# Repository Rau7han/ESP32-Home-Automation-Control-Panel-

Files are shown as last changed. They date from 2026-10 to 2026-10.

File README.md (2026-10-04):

# DIY ESP32 Touchscreen Home Automation Control Panel

A simple DIY home automation project using an ESP32 touchscreen panel and an ESP32 relay node.

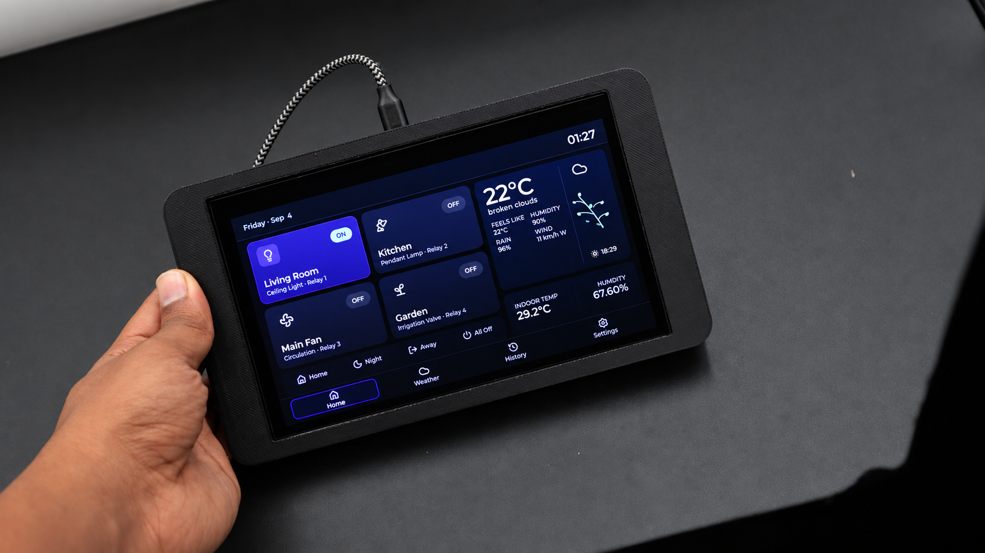
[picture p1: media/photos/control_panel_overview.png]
ESP32 Touchscreen Home Automation Control Panel


## Main Features

- Touchscreen dashboard for controlling home devices
- 4-channel relay control node
- ESP-NOW communication between display and relay board
- DHT22 temperature and humidity support on the relay node

## Hardware / Files Included

- **Display firmware:** `source-code/smart-panel-display/`
- **Relay node firmware:** `source-code/relay-node/`
- **PCB and schematic files (KiCad):** `hardware/pcb/esp32-4-channel-relays/`
- **3D enclosure file:** `hardware/3d/touchscreen_enclosure.3mf`
- **Project photos and diagrams:** `media/photos/`

## Where to Find What

- Use `source-code/` for all Arduino/ESP32 source files.
- Use `hardware/pcb/` for PCB design files.
- Use `hardware/3d/` for enclosure/3D files.
- Use `media/photos/` for project photos and visuals.

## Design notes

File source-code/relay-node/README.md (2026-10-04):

# ESP32 Relay + DHT22 Node

This folder is the relay-side firmware for the Smart Dashboard display.

## Wiring

- DHT22 VCC: 3.3 V
- DHT22 OUT: GPIO 13
- DHT22 GND: GND
- Relay 1: GPIO 26
- Relay 2: GPIO 25
- Relay 3: GPIO 33
- Relay 4: GPIO 32
- Display and relay boards must join the same 2.4 GHz Wi-Fi network

The sketch defaults to active-LOW relay modules. Set `RELAY_ACTIVE_LOW` to `0`
before connecting loads if the module is active HIGH.

## Dependency

Install **DHT sensor library** by Adafruit. Its **Adafruit Unified Sensor**
dependency is installed automatically. This project was compiled with DHT
library 1.4.7 and Arduino-ESP32 3.3.11.

A 3-pin DHT22 module normally includes the required data pull-up resistor. If
using a bare 4-pin sensor, add a 4.7–10 kΩ resistor between OUT and 3.3 V.

## Safety

All relay outputs are driven to OFF before their pins become outputs. Confirm
relay polarity with LEDs or a multimeter before connecting mains voltage.

The OpenWeather key belongs only in the display's private `secrets.h`; this
relay node does not make weather requests.

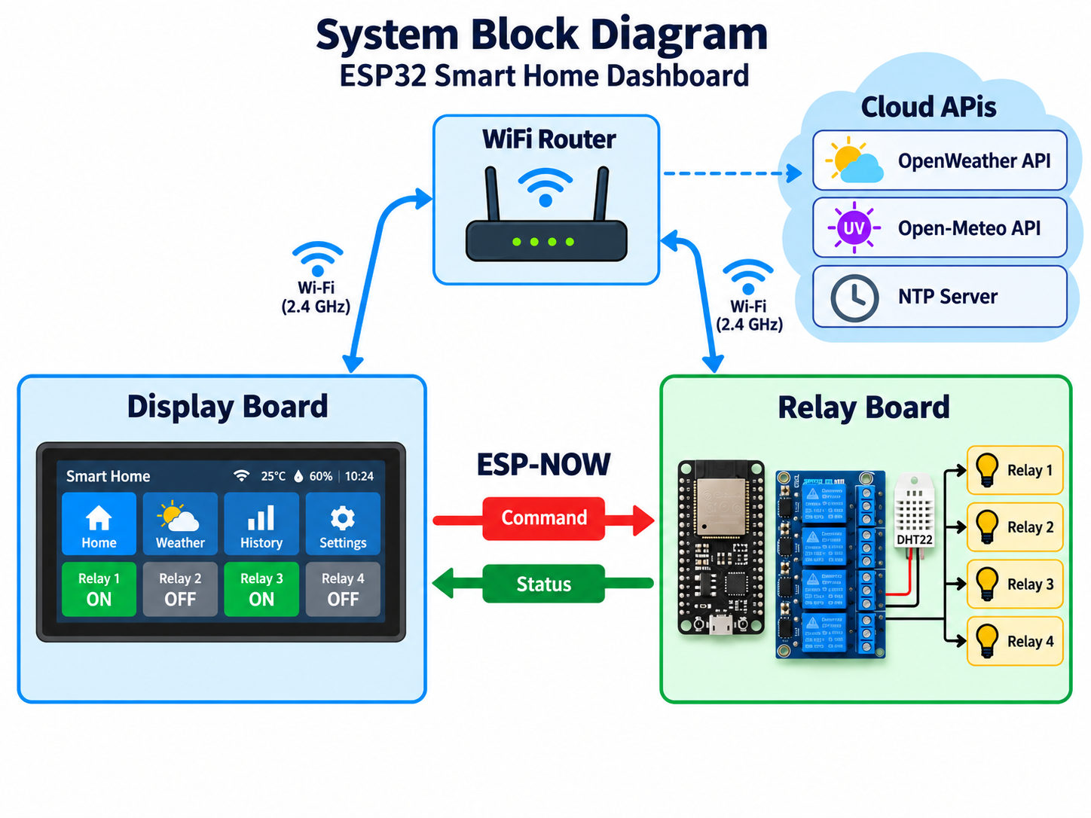
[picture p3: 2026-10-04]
media/photos/concept_render.png

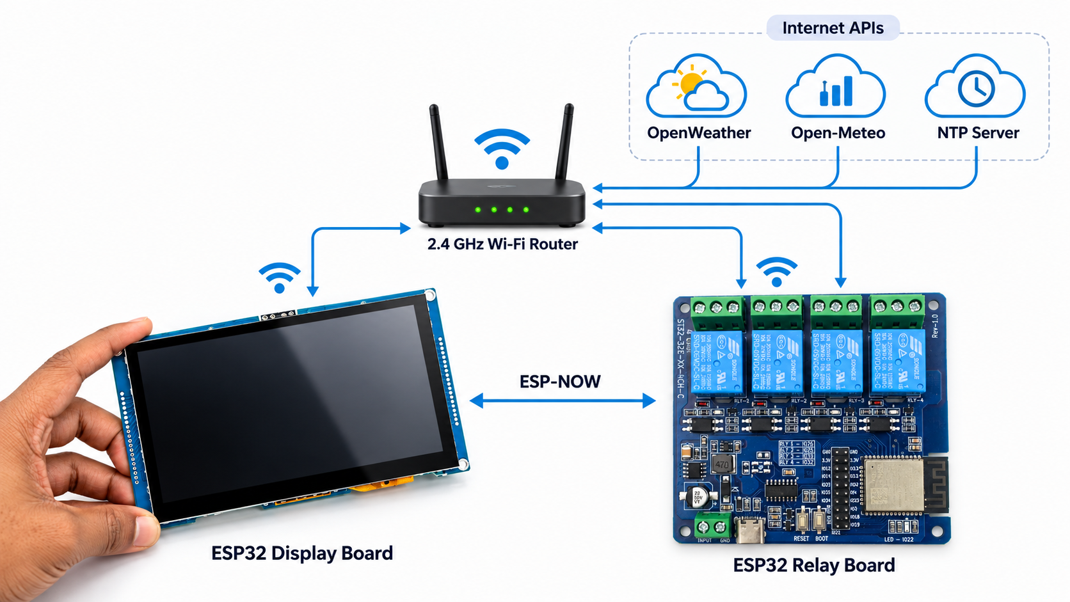
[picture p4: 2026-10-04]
media/photos/system_flow_overview.png

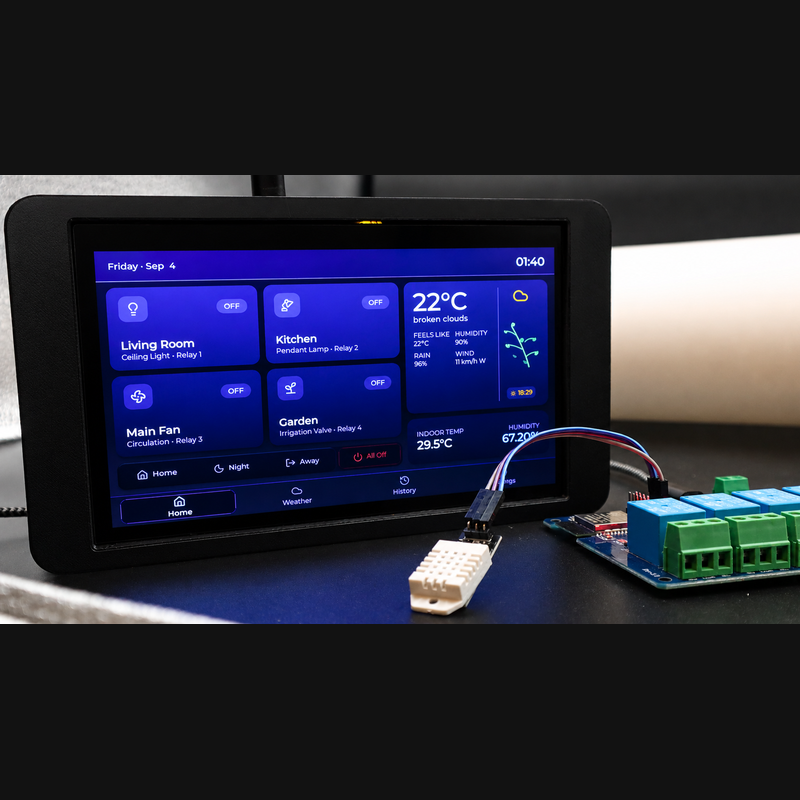
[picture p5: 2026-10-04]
media/photos/smart_home_thumbnail.png

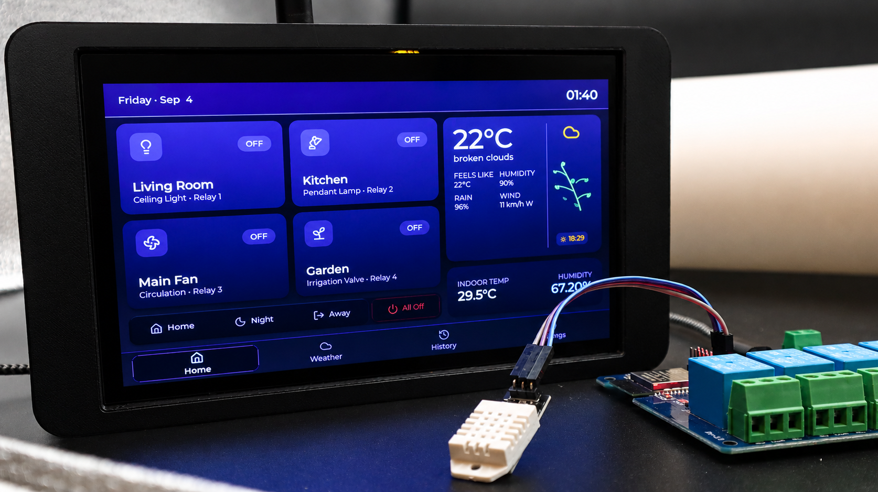
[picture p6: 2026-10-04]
media/photos/esp32_dashboard.png

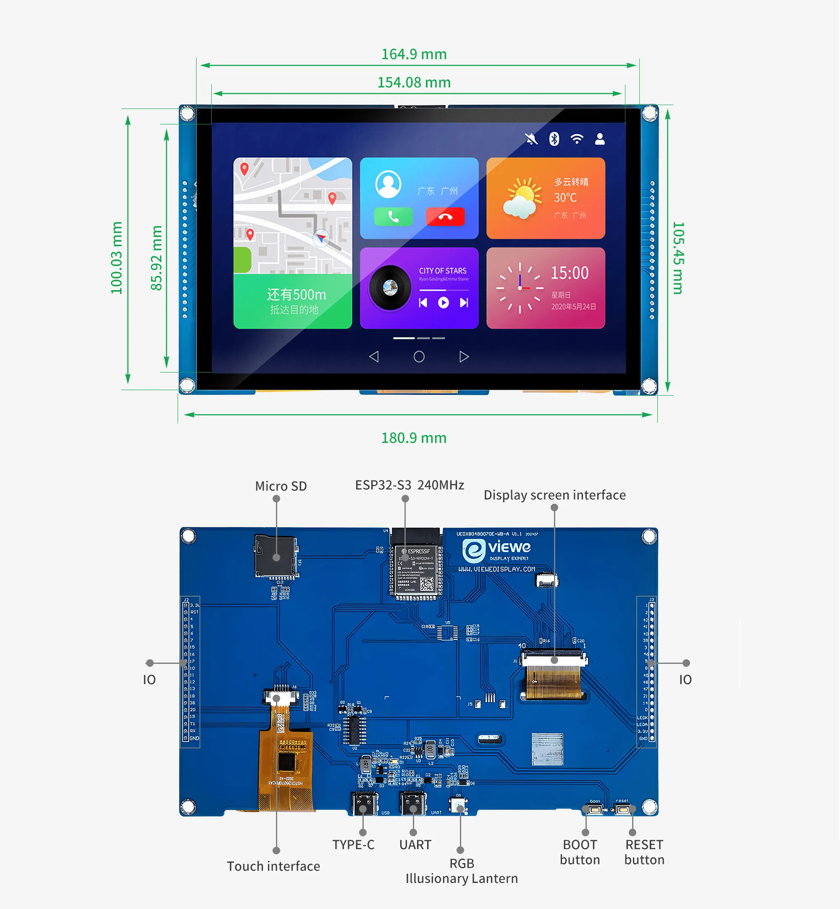
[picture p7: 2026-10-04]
media/photos/product_info_sheet.webp

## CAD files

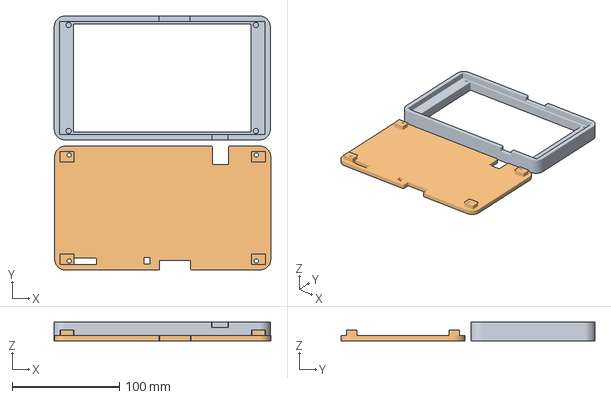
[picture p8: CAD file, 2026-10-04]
hardware/3d/touchscreen_enclosure.3mf
202.0 x 236.9 x 17.6 mm
7 Screen Case_F.stl
UEDX8048007OE-WB-A_back.stl

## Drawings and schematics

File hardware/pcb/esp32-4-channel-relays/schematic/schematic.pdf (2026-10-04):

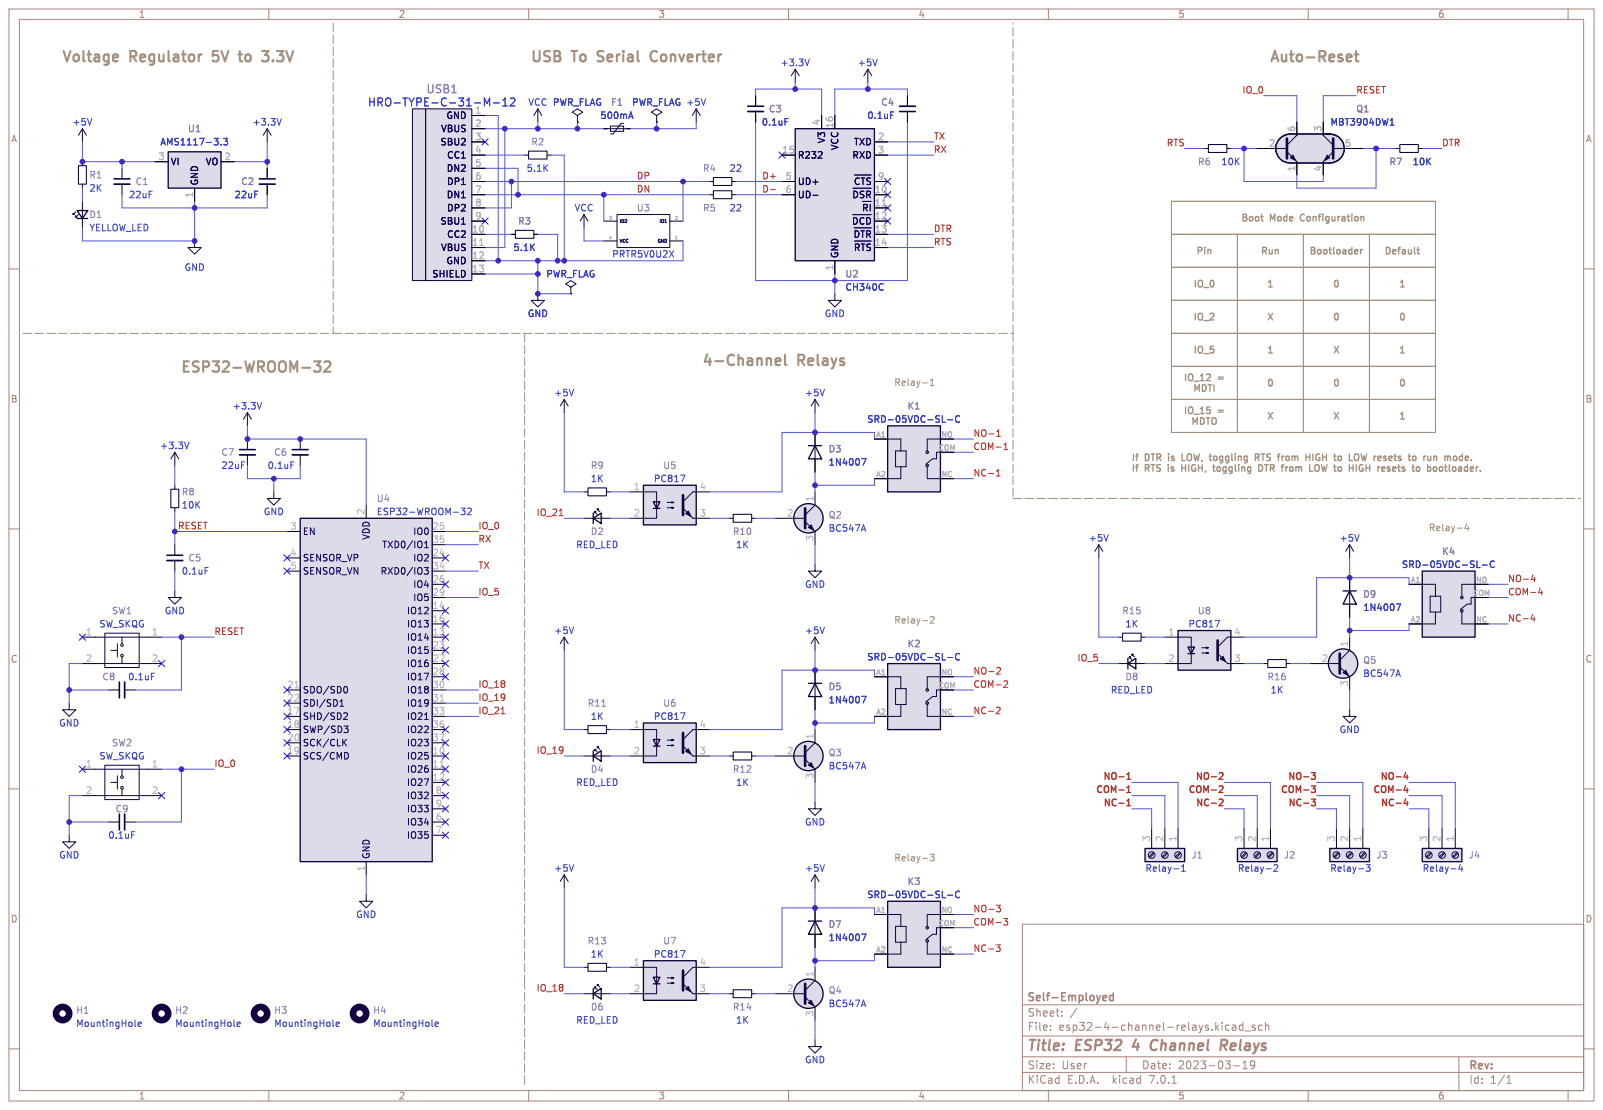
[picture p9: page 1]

GND 1 CC2 10 VBUS 11 GND 12 SHIELD 13 VBUS 2 SBU2 3 CC1 4 DN2 5 DP1 6 DN1 7 DP2 8 SBU1 9 USB1

4 UD+ 5 UD- 6 ~{CTS}9 U2 CH340C GND

1 ~{DSR} 10 ~{RI} 11 ~{DCD} 12 ~{DTR} 13 ~{RTS} 14 R232 15 VCC 16 TXD 2 RXD 3 V3

File: esp32-4-channel-relays.kicad_sch Sheet: / Self-Employed GND

4 UD+ 5 UD- 6 ~{CTS}9 K2 SRD-05VDC-SL-C

If RTS is HIGH, toggling DTR from LOW to HIGH resets to bootloader. Relay-1

If DTR is LOW, toggling RTS from HIGH to LOW resets to run mode.

2 SCK/CLK 20 SDO/SD0 21 SDI/SD1 22

Id: 1/1 Title: ESP32 4 Channel Relays

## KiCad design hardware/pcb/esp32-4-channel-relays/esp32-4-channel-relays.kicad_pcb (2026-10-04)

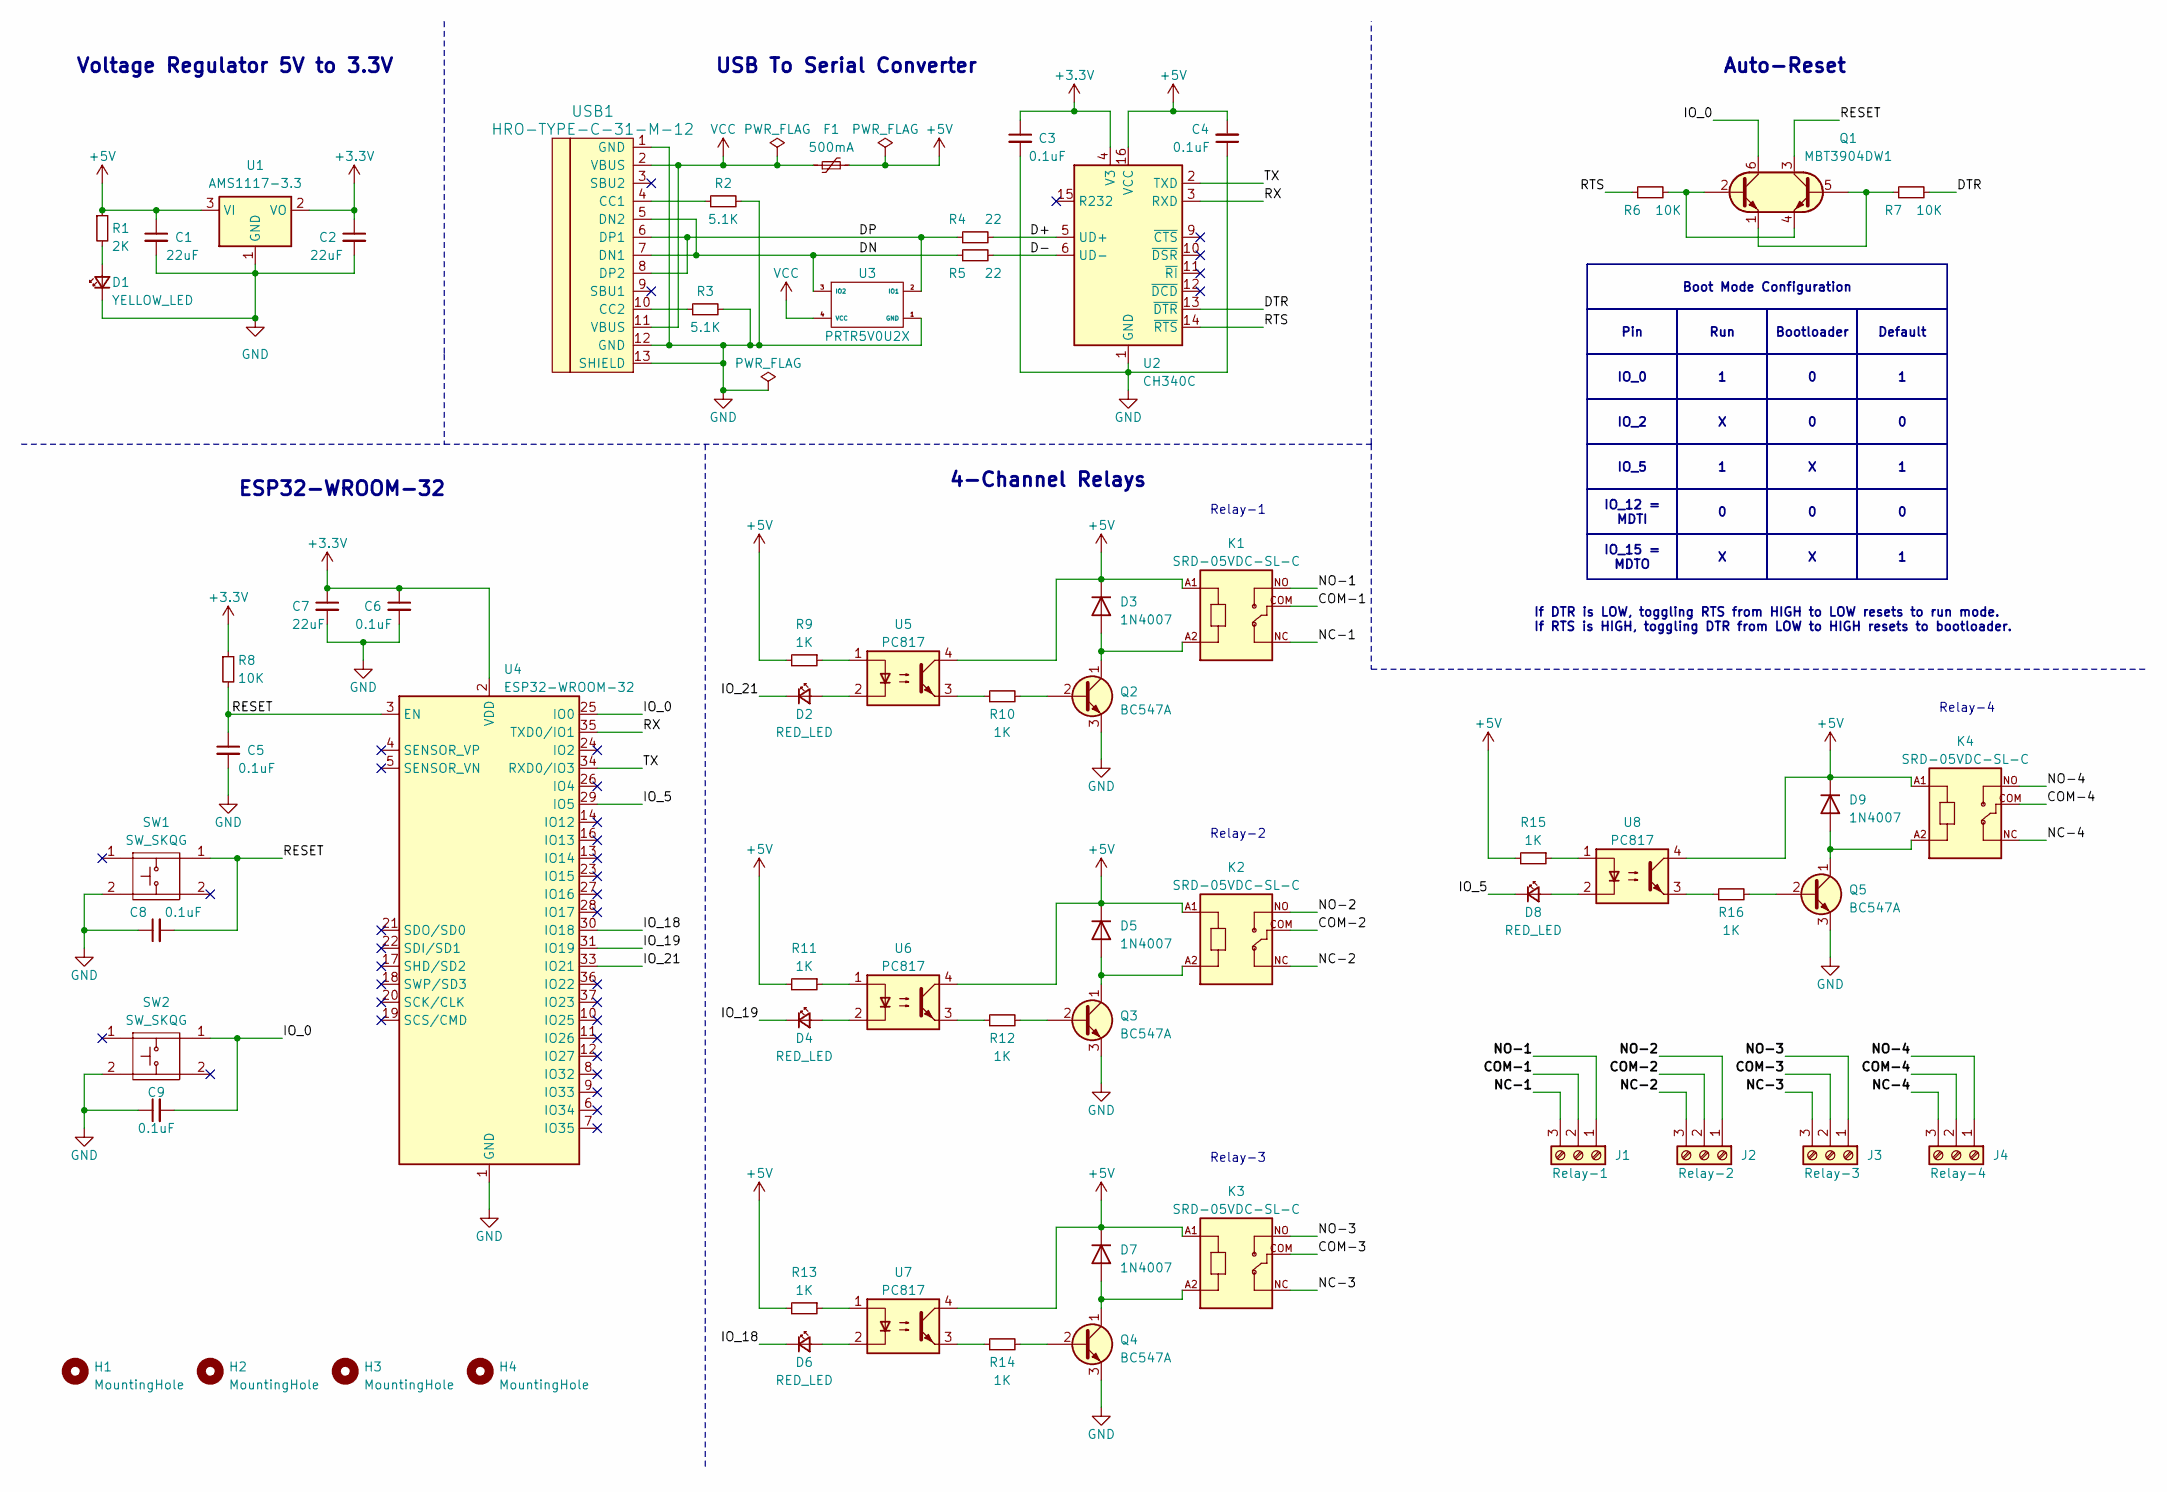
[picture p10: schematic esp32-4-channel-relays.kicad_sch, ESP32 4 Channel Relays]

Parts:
C1, C2, C7: 22uF; C_0805_2012Metric_Pad1.18x1.45mm_HandSolder
C3, C4, C5, C6, C8, C9: 0.1uF; C_0805_2012Metric_Pad1.18x1.45mm_HandSolder
D1: YELLOW_LED; LED_0805_2012Metric_Pad1.15x1.40mm_HandSolder
D2, D4, D6, D8: RED_LED; LED_0805_2012Metric_Pad1.15x1.40mm_HandSolder
D3, D5, D7, D9: 1N4007; D_MELF_Handsoldering
F1: 500mA; Fuse_1206_3216Metric_Pad1.42x1.75mm_HandSolder
H1, H2, H3, H4: MountingHole; MountingHole_3.2mm_M3
J1: Relay-1; TerminalBlock_Phoenix_MKDS-1,5-3-5.08_1x03_P5.08mm_Horizont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
J2: Relay-2; TerminalBlock_Phoenix_MKDS-1,5-3-5.08_1x03_P5.08mm_Horizont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
J3: Relay-3; TerminalBlock_Phoenix_MKDS-1,5-3-5.08_1x03_P5.08mm_Horizont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
J4: Relay-4; TerminalBlock_Phoenix_MKDS-1,5-3-5.08_1x03_P5.08mm_Horizont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
K1, K2, K3, K4: SRD-05VDC-SL-C; RELAY_SRD-05VDC-SL-C
Q1: MBT3904DW1; SOT-363_SC-70-6_Handsoldering
Q2, Q3, Q4, Q5: BC547A; TSOT-23_HandSoldering
R1: 2K; R_0805_2012Metric_Pad1.20x1.40mm_HandSolder
R2, R3: 5.1K; R_0805_2012Metric_Pad1.20x1.40mm_HandSolder
R4, R5: 22; R_0805_2012Metric_Pad1.20x1.40mm_HandSolder
R6, R7, R8: 10K; R_0805_2012Metric_Pad1.20x1.40mm_HandSolder
R9, R10, R11, R12, R13, R14, R15, R16: 1K; R_0805_2012Metric_Pad1.20x1.40mm_HandSolder
SW1, SW2: SW_SKQG; SW_SPST_SKQG_WithStem
U1: AMS1117-3.3; SOT-223-3_TabPin2
U2: CH340C; SOIC-16_3.9x9.9mm_P1.27mm
U3: PRTR5V0U2X; SOT-143_Handsoldering
U4: ESP32-WROOM-32
U5, U6, U7, U8: PC817; SMDIP-4_W7.62mm
USB1: HRO-TYPE-C-31-M-12; HRO-TYPE-C-31-M-12-HandSoldering

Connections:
+3.3V: C2.1, C3.1, C6.1, C7.1, R8.1, U1.2 (VO), U2.4 (V3), U4.2 (VDD)
+5V: C1.1, C4.2, D3.1 (K), D5.1 (K), D7.1 (K), D9.1 (K), F1.2, K1.A1, K2.A1, K3.A1, K4.A1, R1.1, R9.2, R11.2, R13.2, R15.2, U1.3 (VI), U2.16 (VCC), U5.4, U6.4, U7.4, U8.4
/COM-1: J1.2, K1.COM
/COM-2: J2.2, K2.COM
/COM-3: J3.2, K3.COM
/COM-4: J4.2, K4.COM
/D+: R4.2, U2.5 (UD+)
/D-: R5.2, U2.6 (UD-)
/DN: R5.1, U3.3 (IO2), USB1.5 (DN2), USB1.7 (DN1)
/DP: R4.1, U3.2 (IO1), USB1.6 (DP1), USB1.8 (DP2)
/DTR: R7.2, U2.13 (~DTR)
/IO_0: C9.2, Q1.6 (C1), SW2.1, U4.25 (IO0)
/IO_5: D8.1 (K), U4.29 (IO5)
/IO_18: D6.1 (K), U4.30 (IO18)
/IO_19: D4.1 (K), U4.31 (IO19)
/IO_21: D2.1 (K), U4.33 (IO21)
/NC-1: J1.3, K1.NC
/NC-2: J2.3, K2.NC
/NC-3: J3.3, K3.NC
/NC-4: J4.3, K4.NC
/NO-1: J1.1, K1.NO
/NO-2: J2.1, K2.NO
/NO-3: J3.1, K3.NO
/NO-4: J4.1, K4.NO
/RESET: C5.1, C8.2, Q1.3 (C2), R8.2, SW1.1, U4.3 (EN)
/RTS: R6.1, U2.14 (~RTS)
/RX: U2.3 (RXD), U4.35 (TXD0/IO1)
/TX: U2.2 (TXD), U4.34 (RXD0/IO3)
GND: C1.2, C2.2, C3.2, C4.1, C5.2, C6.2, C7.2, C8.1, C9.1, D1.1 (K), Q2.3 (E), Q3.3 (E), Q4.3 (E), Q5.3 (E), R2.2, R3.2, SW1.2, SW2.2, U1.1 (GND), U2.1 (GND), U3.1 (GND), U4.1 (GND), U4.15 (GND), U4.38 (GND), U4.39 (GND), USB1.1 (GND), USB1.12 (GND), USB1.13 (SHIELD)
unnamed: D1.2 (A), R1.2
unnamed: D2.2 (A), U5.2
unnamed: D3.2 (A), K1.A2, Q2.1 (C)
unnamed: D4.2 (A), U6.2
unnamed: D5.2 (A), K2.A2, Q3.1 (C)
unnamed: D6.2 (A), U7.2
unnamed: D7.2 (A), K3.A2, Q4.1 (C)
unnamed: D8.2 (A), U8.2
unnamed: D9.2 (A), K4.A2, Q5.1 (C)
unnamed: Q1.2 (B1), Q1.4 (E2), R6.2
unnamed: Q1.1 (E1), Q1.5 (B2), R7.1
unnamed: Q2.2 (B), R10.2
unnamed: Q3.2 (B), R12.2
unnamed: Q4.2 (B), R14.2
unnamed: Q5.2 (B), R16.2
unnamed: R9.1, U5.1
unnamed: R10.1, U5.3
unnamed: R11.1, U6.1
unnamed: R12.1, U6.3
unnamed: R13.1, U7.1
unnamed: R14.1, U7.3
unnamed: R15.1, U8.1
unnamed: R16.1, U8.3
unnamed: R2.1, USB1.4 (CC1)
unnamed: R3.1, USB1.10 (CC2)
VCC: F1.1, U3.4 (VCC), USB1.2 (VBUS), USB1.11 (VBUS)

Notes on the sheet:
Default
IO_2
IO_15 = MDTO
Bootloader
IO_0
IO_12 = MDTI
Run
Boot Mode Configuration
IO_5
Pin
Voltage Regulator 5V to 3.3V
4-Channel Relays
Relay-1
Relay-4
Relay-3
Relay-2
Auto-Reset
ESP32-WROOM-32
If DTR is LOW, toggling RTS from HIGH to LOW resets to run mode. If RTS is HIGH, toggling DTR from LOW to HIGH resets to bootloader.
USB To Serial Converter

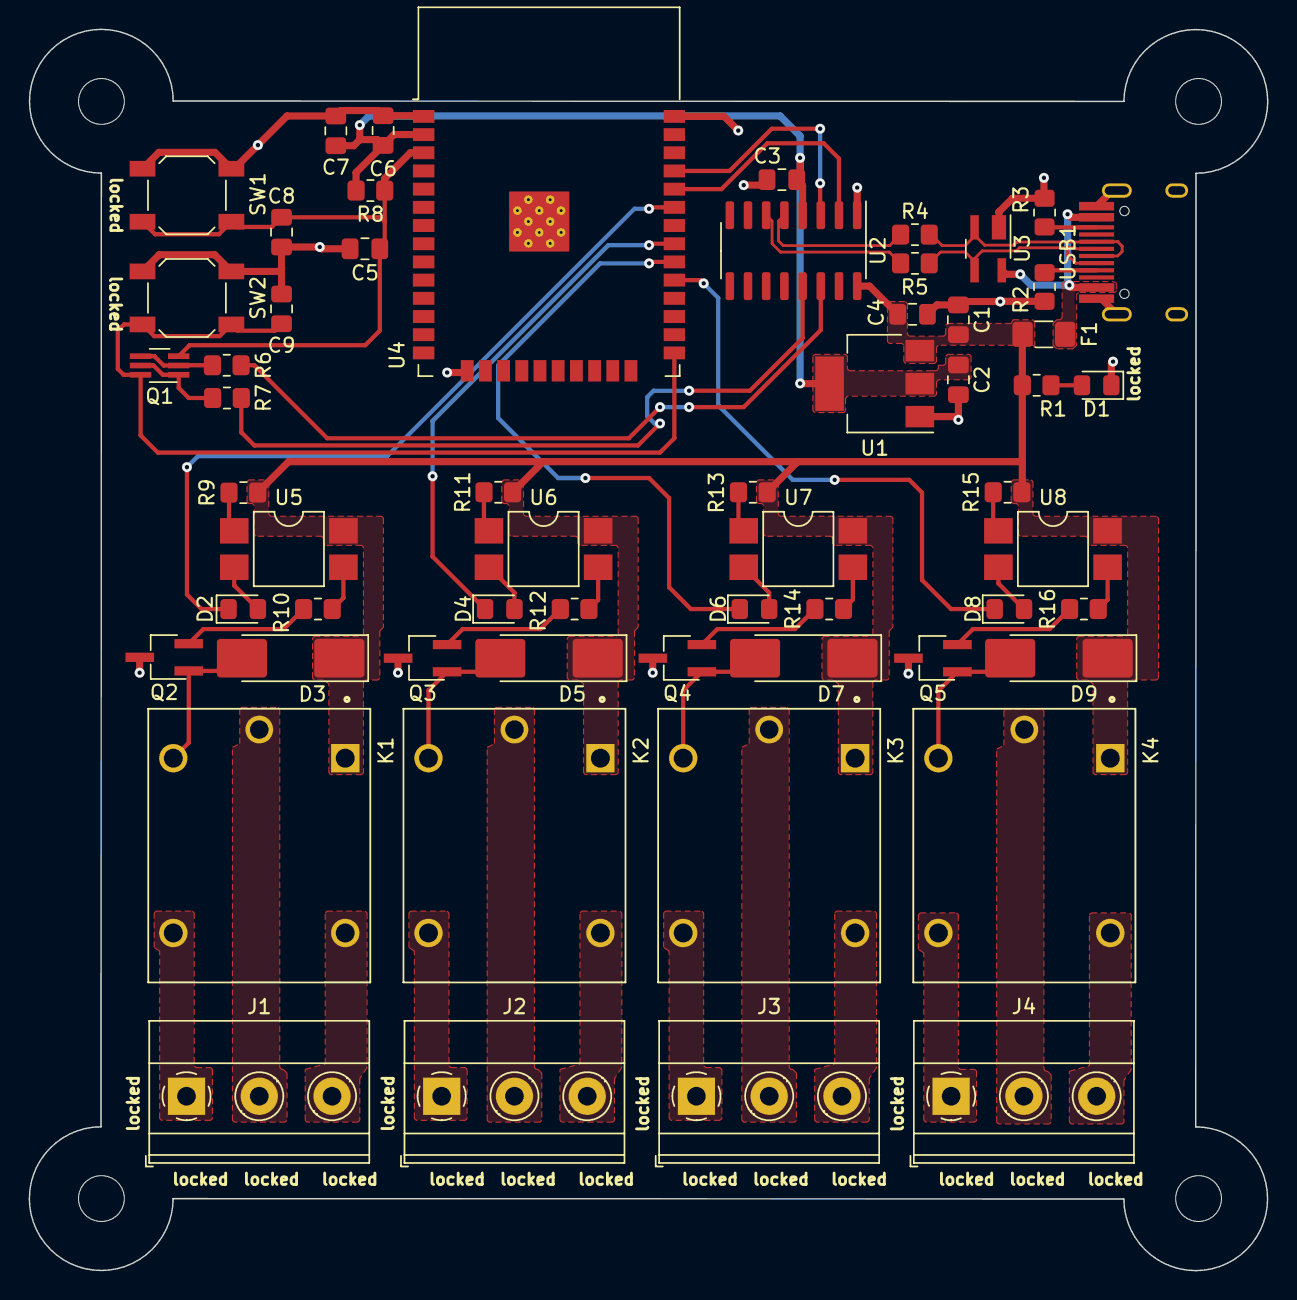
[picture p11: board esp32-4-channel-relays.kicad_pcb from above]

Board: 2 copper layers, 86.4 x 86.6 mm, 63 parts (0 on the bottom side), 55 nets.

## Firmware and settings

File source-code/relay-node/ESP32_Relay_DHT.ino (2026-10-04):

/**
 * ESP32 relay and DHT22 node for the Smart Dashboard.
 *
 * Hardware:
 *   DHT22 data GPIO 13
 *   Relay outputs GPIO 26, 25, 33, 32
 *
 * The node joins the same Wi-Fi network as the display so ESP-NOW uses the
 * router channel. Relay outputs change only after a valid command from the
 * configured display MAC. Every command is followed by a confirmed status
 * packet; periodic status packets keep the display's online state fresh.
 */

#include <Arduino.h>
#include <WiFi.h>
#include <esp_now.h>
#include <esp_mac.h>
#include <DHT.h>

#include "espnow_protocol.h"
#include "relay_secrets.h"

#define DHT_PIN 13
#define DHT_TYPE DHT22

#define RELAY1 26
#define RELAY2 25
#define RELAY3 33
#define RELAY4 32

/* Most opto-isolated relay modules are active LOW. Change this to 0 before
 * connecting loads if your module is active HIGH. Boot always requests OFF. */
#define RELAY_ACTIVE_LOW 1

static constexpr uint8_t RELAY_COUNT = 4;
static constexpr uint8_t RELAY_MASK_ALL = 0x0F;
static constexpr uint32_t STATUS_INTERVAL_MS = 2000;
static constexpr uint32_t SENSOR_INTERVAL_MS = 5000;
static constexpr uint32_t SENSOR_STALE_MS = 15000;

static const uint8_t RELAY_PINS[RELAY_COUNT] = {
    RELAY1, RELAY2, RELAY3, RELAY4
};

static const uint8_t DISPLAY_ESP32_MAC[6] = {
    0xFC, 0x01, 0x2C, 0xD4, 0x9C, 0x38
};

static const uint8_t EXPECTED_RELAY_MAC[6] = {
    0xC0, 0x5D, 0x89, 0xF5, 0xAD, 0xFC
};

enum CommandKind : uint8_t {
    COMMAND_RELAY,
    COMMAND_SCENE,
    COMMAND_STATUS
};

struct QueuedCommand {
    CommandKind kind;
    uint8_t relayIndex;
    uint8_t desiredState;
    uint8_t relayMask;
    uint32_t sequence;
};

struct SensorSnapshot {
    uint8_t validMask;
    int16_t temperatureCentiC;
    uint16_t humidityCentiPercent;
    uint32_t sampledAtMs;
};

static QueueHandle_t commandQueue = nullptr;
static DHT dht(DHT_PIN, DHT_TYPE);

static portMUX_TYPE sensorMux = portMUX_INITIALIZER_UNLOCKED;
static SensorSnapshot sensorSnapshot = {};
static volatile bool sensorStatusDirty = false;

static uint8_t confirmedRelayMask = 0;
static bool espNowReady = false;
static bool wifiWasConnected = false;
static uint32_t lastStatusSentMs = 0;
static uint32_t lastEspNowAttemptMs = 0;
static uint32_t lastConfirmedSequence = 0;

static bool macMatches(const uint8_t *a, const uint8_t *b)
{
    return a != nullptr && b != nullptr && memcmp(a, b, 6) == 0;
}

static uint8_t relayOffLevel()
{
    return RELAY_ACTIVE_LOW ? HIGH : LOW;
}

static uint8_t relayOnLevel()
{
    return RELAY_ACTIVE_LOW ? LOW : HIGH;
}

static void initializeRelayOutputs()
{
    confirmedRelayMask = 0;
    for (uint8_t i = 0; i < RELAY_COUNT; i++) {
        /* Set the output latch before enabling output mode to avoid an ON pulse. */
        digitalWrite(RELAY_PINS[i], relayOffLevel());
        pinMode(RELAY_PINS[i], OUTPUT);
        digitalWrite(RELAY_PINS[i], relayOffLevel());
    }
}

static void applyRelayMask(uint8_t mask)
{
    mask &= RELAY_MASK_ALL;
    for (uint8_t i = 0; i < RELAY_COUNT; i++) {
        bool on = (mask & (1U << i)) != 0;
        digitalWrite(RELAY_PINS[i], on ? relayOnLevel() : relayOffLevel());
    }
    confirmedRelayMask = mask;
}

static void sensorTask(void *parameter)
{
    (void)parameter;
    for (;;) {
        float humidity = dht.readHumidity();
        float temperature = dht.readTemperature();

        if (isnan(humidity) || isnan(temperature)) {
            Serial.println("DHT22 read failed; retaining last valid sample");
        } else {
            SensorSnapshot next = {};
            next.validMask = SENSOR_TEMP_VALID | SENSOR_HUMIDITY_VALID;
            next.temperatureCentiC =
                (int16_t)lroundf(temperature * 100.0f);
            humidity = constrain(humidity, 0.0f, 100.0f);
            next.humidityCentiPercent =
                (uint16_t)lroundf(humidity * 100.0f);
            next.sampledAtMs = millis();

            portENTER_CRITICAL(&sensorMux);
            sensorSnapshot = next;
            sensorStatusDirty = true;
            portEXIT_CRITICAL(&sensorMux);
        }

        vTaskDelay(pdMS_TO_TICKS(SENSOR_INTERVAL_MS));
    }
}

static void espNowSendCallback(
    const esp_now_send_info_t *info,
    esp_now_send_status_t status)
{
    (void)info;
    if (status != ESP_NOW_SEND_SUCCESS) {
        Serial.println("ESP-NOW status delivery failed");
    }
}

static void espNowReceiveCallback(
    const esp_now_recv_info_t *info,
    const uint8_t *data,
    int length)
{
    if (info == nullptr ||
        data == nullptr ||
        commandQueue == nullptr ||
        !macMatches(info->src_addr, DISPLAY_ESP32_MAC) ||
        length < 2 ||
        data[0] != ESPNOW_PROTOCOL_VERSION) {
        return;
    }

    QueuedCommand command = {};
    switch (data[1]) {
        case MSG_RELAY_COMMAND: {
            if (length != (int)sizeof(RelayCommandPacket)) return;
            RelayCommandPacket packet;
            memcpy(&packet, data, sizeof(packet));
            if (packet.relayIndex >= RELAY_COUNT || packet.desiredState > 1) return;
            command.kind = COMMAND_RELAY;
            command.relayIndex = packet.relayIndex;
            command.desiredState = packet.desiredState;
            command.sequence = packet.sequence;
            break;
        }
        case MSG_SCENE_COMMAND: {
            if (length != (int)sizeof(SceneCommandPacket)) return;
            SceneCommandPacket packet;
            memcpy(&packet, data, sizeof(packet));
            command.kind = COMMAND_SCENE;
            command.relayMask = packet.desiredRelayMask & RELAY_MASK_ALL;
            command.sequence = packet.sequence;
            break;
        }
        case MSG_STATUS_REQUEST: {
            if (length != (int)sizeof(StatusRequestPacket)) return;
            StatusRequestPacket packet;
            memcpy(&packet, data, sizeof(packet));
            command.kind = COMMAND_STATUS;
            command.sequence = packet.sequence;
            break;
        }
        default:
            return;
    }

    xQueueSend(commandQueue, &command, 0);
}

static bool initializeEspNow()
{
    if (espNowReady) return true;
    if (esp_now_init() != ESP_OK) {
        Serial.println("ESP-NOW initialization failed");
        return false;
    }

    if (esp_now_register_send_cb(espNowSendCallback) != ESP_OK ||
        esp_now_register_recv_cb(espNowReceiveCallback) != ESP_OK) {
        Serial.println("ESP-NOW callback registration failed");
        esp_now_deinit();
        return false;
    }

    esp_now_peer_info_t peer = {};
    memcpy(peer.peer_addr, DISPLAY_ESP32_MAC, 6);
    peer.channel = WiFi.channel();
    peer.ifidx = WIFI_IF_STA;
    peer.encrypt = false;

    esp_err_t result = esp_now_add_peer(&peer);
    espNowReady = result == ESP_OK || result == ESP_ERR_ESPNOW_EXIST;
    Serial.printf(
        "Display peer registration: %s (%d), channel %u\n",
        espNowReady ? "OK" : "FAILED",
        result,
        (unsigned)WiFi.channel());
    if (!espNowReady) esp_now_deinit();
    return espNowReady;
}

static void sendConfirmedStatus(uint32_t sequence)
{
    if (!espNowReady) return;

    SensorSnapshot sensor;
    portENTER_CRITICAL(&sensorMux);
    sensor = sensorSnapshot;
    portEXIT_CRITICAL(&sensorMux);

    if (sensor.sampledAtMs == 0 ||
        millis() - sensor.sampledAtMs > SENSOR_STALE_MS) {
        sensor.validMask = 0;
    }

    RelaySensorStatusPacket packet = {};
    packet.version = ESPNOW_PROTOCOL_VERSION;
    packet.type = MSG_RELAY_SENSOR_STATUS;
    packet.relayMask = confirmedRelayMask;
    packet.sensorValidMask = sensor.validMask;
    packet.sequence = sequence;
    packet.indoorTemperatureCentiC = sensor.temperatureCentiC;
    packet.indoorHumidityCentiPercent = sensor.humidityCentiPercent;
    packet.relayNodeUptimeMs = millis();

    esp_now_send(
        DISPLAY_ESP32_MAC,
        reinterpret_cast<const uint8_t *>(&packet),
        sizeof(packet));
    lastStatusSentMs = millis();
}

static void processCommandQueue()
{
    QueuedCommand command;
    while (commandQueue != nullptr &&
           xQueueReceive(commandQueue, &command, 0) == pdTRUE) {
        switch (command.kind) {
            case COMMAND_RELAY: {
                uint8_t bit = 1U << command.relayIndex;
                uint8_t desiredMask = command.desiredState
                    ? (confirmedRelayMask | bit)
                    : (confirmedRelayMask & ~bit);
                applyRelayMask(desiredMask);
                lastConfirmedSequence = command.sequence;
                Serial.printf(
                    "Relay %u confirmed %s, mask=0x%02X\n",
                    command.relayIndex + 1,
                    command.desiredState ? "ON" : "OFF",
                    confirmedRelayMask);
                sendConfirmedStatus(command.sequence);
                break;
            }
            case COMMAND_SCENE:
                applyRelayMask(command.relayMask);
                lastConfirmedSequence = command.sequence;
                Serial.printf(
                    "Scene confirmed, mask=0x%02X\n",
                    confirmedRelayMask);
                sendConfirmedStatus(command.sequence);
                break;
            case COMMAND_STATUS:
                sendConfirmedStatus(command.sequence);
                break;
        }
    }
}

static void initializeSensor()
{
    dht.begin();
    BaseType_t result = xTaskCreate(
        sensorTask, "dht22", 3072, nullptr, 1, nullptr);
    if (result == pdPASS) {
        Serial.printf("DHT22 ready on GPIO %u\n", DHT_PIN);
    } else {
        Serial.println("ERROR: DHT22 task creation failed");
    }
}

void setup()
{
    Serial.begin(115200);
    delay(500);
    Serial.println("\nESP32 Relay + DHT22 Node");
    Serial.printf(
        "Relay pins: %u, %u, %u, %u (%s)\n",
        RELAY1, RELAY2, RELAY3, RELAY4,
        RELAY_ACTIVE_LOW ? "active LOW" : "active HIGH");

    initializeRelayOutputs();
    initializeSensor();

    commandQueue = xQueueCreate(12, sizeof(QueuedCommand));
    if (commandQueue == nullptr) {
        Serial.println("ERROR: command queue allocation failed");
    }

    WiFi.mode(WIFI_STA);

    /* WiFi.macAddress() returns zeros until the Wi-Fi stack finishes starting,
     * so read the eFuse address directly. */
    uint8_t actualMac[6];
    esp_read_mac(actualMac, ESP_MAC_WIFI_STA);
    Serial.printf(
        "Relay STA MAC: %02X:%02X:%02X:%02X:%02X:%02X\n",
        actualMac[0], actualMac[1], actualMac[2],
        actualMac[3], actualMac[4], actualMac[5]);
    Serial.println("Expected relay MAC: C0:5D:89:F5:AD:FC");
    Serial.println("Display peer MAC: FC:01:2C:D4:9C:38");

    if (!macMatches(actualMac, EXPECTED_RELAY_MAC)) {
        Serial.println("WARNING: this board MAC differs from the configured relay peer MAC");
    }

    WiFi.setAutoReconnect(true);
    WiFi.setSleep(false);
    WiFi.begin(WIFI_SSID, WIFI_PASSWORD);
    Serial.println("Wi-Fi connection started");
}

void loop()
{
    uint32_t now = millis();
    bool connected = WiFi.status() == WL_CONNECTED;

    if (connected && !wifiWasConnected) {
        wifiWasConnected = true;
        Serial.printf(
            "Wi-Fi connected, IP=%s, channel=%u\n",
            WiFi.localIP().toString().c_str(),
            (unsigned)WiFi.channel());
        initializeEspNow();
        lastEspNowAttemptMs = now;
        sendConfirmedStatus(lastConfirmedSequence);
    } else if (!connected && wifiWasConnected) {
        wifiWasConnected = false;
        espNowReady = false;
        esp_now_deinit();
        Serial.println("Wi-Fi disconnected; relays keep their confirmed states");
    }

    if (connected && !espNowReady &&
        now - lastEspNowAttemptMs >= 5000) {
        lastEspNowAttemptMs = now;
        initializeEspNow();
    }

    processCommandQueue();

    if (espNowReady &&
        (sensorStatusDirty || now - lastStatusSentMs >= STATUS_INTERVAL_MS)) {
        sensorStatusDirty = false;
        sendConfirmedStatus(lastConfirmedSequence);
    }

    delay(10);
}

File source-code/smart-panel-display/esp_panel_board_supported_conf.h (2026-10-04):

/*
 * SPDX-FileCopyrightText: 2023-2025 Espressif Systems (Shanghai) CO LTD
 *
 * SPDX-License-Identifier: Apache-2.0
 */
/**
 * @file  esp_panel_board_supported_conf.h
 * @brief Configuration file for supported ESP development boards
 *
 * This file contains configuration options for various supported development boards using ESP Panel.
 * Users can select their specific board by uncommenting the corresponding macro definition.
 */

#pragma once

/**
 * @brief Flag to enable supported board configuration (0/1)
 *
 * Set to `1` to enable supported board configuration, `0` to disable
 */
#define ESP_PANEL_BOARD_DEFAULT_USE_SUPPORTED       (1)

#if ESP_PANEL_BOARD_DEFAULT_USE_SUPPORTED
/**
 * @brief Board selection macros
 *
 * Uncomment one of the following macros to select a supported development board. Multiple macros enabled
 * simultaneously will trigger a compilation error.
 */

/*
 * Espressif (https://www.espressif.com/en/products/devkits):
 *
 *  -BOARD_ESPRESSIF_ESP32_C3_LCDKIT (ESP32-C3-LCDkit): https://docs.espressif.com/projects/esp-dev-kits/en/latest/esp32c3/esp32-c3-lcdkit/index.html
 *  -BOARD_ESPRESSIF_ESP32_S3_BOX (ESP32-S3-Box): https://github.com/espressif/esp-box/tree/master
 *  -BOARD_ESPRESSIF_ESP32_S3_BOX_3 (ESP32-S3-Box-3 & ESP32-S3-Box-3B): https://github.com/espressif/esp-box/tree/master
 *  -BOARD_ESPRESSIF_ESP32_S3_BOX_3_BETA (ESP32-S3-Box-3(beta)): https://github.com/espressif/esp-box/tree/c4c954888e11250423f083df0067d99e22d59fbe
 *  -BOARD_ESPRESSIF_ESP32_S3_BOX_LITE (ESP32-S3-Box-Lite): https://github.com/espressif/esp-box/tree/master
 *  -BOARD_ESPRESSIF_ESP32_S3_EYE (ESP32-S3-EYE): https://github.com/espressif/esp-who/blob/master/docs/en/get-started/ESP32-S3-EYE_Getting_Started_Guide.md
 *  -BOARD_ESPRESSIF_ESP32_S3_KORVO_2 (ESP32-S3-Korvo-2): https://docs.espressif.com/projects/esp-adf/en/latest/design-guide/dev-boards/user-guide-esp32-s3-korvo-2.html
 *  -BOARD_ESPRESSIF_ESP32_S3_LCD_EV_BOARD (ESP32-S3-LCD-EV-Board(v1.1-v1.4)): https://docs.espressif.com/projects/esp-dev-kits/en/latest/esp32s3/esp32-s3-lcd-ev-board/user_guide_v1.4.html
 *  -BOARD_ESPRESSIF_ESP32_S3_LCD_EV_BOARD_V1_5 (ESP32-S3-LCD-EV-Board(v1.5)): https://docs.espressif.com/projects/esp-dev-kits/en/latest/esp32s3/esp32-s3-lcd-ev-board/user_guide.html
 *  -BOARD_ESPRESSIF_ESP32_S3_LCD_EV_BOARD_2 (ESP32-S3-LCD-EV-Board-2(v1.1-v1.4))): https://docs.espressif.com/projects/esp-dev-kits/en/latest/esp32s3/esp32-s3-lcd-ev-board/user_guide_v1.4.html
 *  -BOARD_ESPRESSIF_ESP32_S3_LCD_EV_BOARD_2_V1_5 (ESP32-S3-LCD-EV-Board-2(v1.5)): https://docs.espressif.com/projects/esp-dev-kits/en/latest/esp32s3/esp32-s3-lcd-ev-board/user_guide.html
 *  -BOARD_ESPRESSIF_ESP32_S3_USB_OTG (ESP32-S3-USB-OTG): https://docs.espressif.com/projects/esp-dev-kits/en/latest/esp32s3/esp32-s3-usb-otg/index.html
 *  -BOARD_ESPRESSIF_ESP32_P4_FUNCTION_EV_BOARD (ESP32-P4-Function-EV-Board): https://docs.espressif.com/projects/esp-dev-kits/en/latest/esp32p4/esp32-p4-function-ev-board/index.html
 */
// #define BOARD_ESPRESSIF_ESP32_C3_LCDKIT
// #define BOARD_ESPRESSIF_ESP32_S3_BOX
// #define BOARD_ESPRESSIF_ESP32_S3_BOX_3
// #define BOARD_ESPRESSIF_ESP32_S3_BOX_3_BETA
// #define BOARD_ESPRESSIF_ESP32_S3_BOX_LITE
// #define BOARD_ESPRESSIF_ESP32_S3_EYE
// #define BOARD_ESPRESSIF_ESP32_S3_KORVO_2
// #define BOARD_ESPRESSIF_ESP32_S3_LCD_EV_BOARD
// #define BOARD_ESPRESSIF_ESP32_S3_LCD_EV_BOARD_V1_5
// #define BOARD_ESPRESSIF_ESP32_S3_LCD_EV_BOARD_2
// #define BOARD_ESPRESSIF_ESP32_S3_LCD_EV_BOARD_2_V1_5
// #define BOARD_ESPRESSIF_ESP32_S3_USB_OTG
// #define BOARD_ESPRESSIF_ESP32_P4_FUNCTION_EV_BOARD

/*
 * Elecrow (https://www.elecrow.com):
 *
 *  -BOARD_ELECROW_CROWPANEL_7_0 (ELECROW_CROWPANEL_7_0): https://www.elecrow.com/esp32-display-7-inch-hmi-display-rgb-tft-lcd-touch-screen-support-lvgl.html
 */
// #define BOARD_ELECROW_CROWPANEL_7_0

/*
 * M5Stack (https://m5stack.com/):
 *
 *  -BOARD_M5STACK_M5CORE2 (M5STACK_M5CORE2): https://docs.m5stack.com/en/core/core2
 *  -BOARD_M5STACK_M5DIAL (M5STACK_M5DIAL): https://docs.m5stack.com/en/core/M5Dial
 *  -BOARD_M5STACK_M5CORES3 (M5STACK_M5CORES3): https://docs.m5stack.com/en/core/CoreS3
 */
// #define BOARD_M5STACK_M5CORE2
// #define BOARD_M5STACK_M5DIAL
// #define BOARD_M5STACK_M5CORES3

/*
 * Shenzhen Jingcai Intelligent Supported Boards (https://www.displaysmodule.com/):
 *
 *  -BOARD_JINGCAI_ESP32_4848S040C_I_Y_3 (ESP32-4848S040C_I_Y_3):
 *      - https://www.displaysmodule.com/sale-41828962-experience-the-power-of-the-esp32-display-module-sku-esp32-4848s040c-i-y-3.html
 *      - http://pan.jczn1688.com/directlink/1/ESP32%20module/4.0inch_ESP32-4848S040.zip
 *  -BOARD_JINGCAI_JC8048W550C (JC8048W550C):
 *      - https://www.displaysmodule.com/sale-43987867-capacitive-touch-advanced-tft-hmi-display-module-jc8048w550-800-480-pixel-resolution-st7262-driver-c.html
 */
// #define BOARD_JINGCAI_ESP32_4848S040C_I_Y_3
// #define BOARD_JINGCAI_JC8048W550C
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

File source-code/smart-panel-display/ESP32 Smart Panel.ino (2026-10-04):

/**
 * VIEWE UEDX80480070 7.0-inch ESP32-S3 Touch Display
 * Resolution: 800 x 480, IPS RGB interface / Touch: GT911 (I2C) / MCU: ESP32-S3
 *
 * Smart Home Panel UI (LVGL v8), Phase 1 display firmware.
 * Relay GPIO and DHT22 acquisition run on the separate relay-node firmware.
 */

#include <Arduino.h>
#include <Preferences.h>
#include <math.h>
#include <limits.h>
#include <WiFi.h>
#include <HTTPClient.h>
#include <ArduinoJson.h>
#include <esp_now.h>
#include <esp_mac.h>
#include <time.h>
#include <esp_display_panel.hpp>
#include <lvgl.h>
#include "lvgl_v8_port.h"
#include "dashboard_icons.h"
#include "espnow_protocol.h"

#if __has_include("secrets.h")
#include "secrets.h"
#define DASHBOARD_HAS_SECRETS 1
#else
#define DASHBOARD_HAS_SECRETS 0
#define WIFI_SSID ""
#define WIFI_PASSWORD ""
#define OPENWEATHER_KEY ""
#define WEATHER_LATITUDE ""
#define WEATHER_LONGITUDE ""
#define TIMEZONE_INFO "UTC0"
#endif

using namespace esp_panel::drivers;
using namespace esp_panel::board;

/* Only the degree sign and the bullet exist outside ASCII in the built-in
   fonts. Kept as macros so an adjacent hex digit cannot extend the escape. */
#define DEG  "\xC2\xB0"
#define MDOT " \xE2\x80\xA2 "

/* Type scale. Sizes below 12 px are deliberately absent: small grey text was
   unreadable on this panel, so 12 px is the floor and captions use text2. */
#define F_CAP   &lv_font_montserrat_12
#define F_BODY  &lv_font_montserrat_14
#define F_TITLE &lv_font_montserrat_16
#define F_RELAY &lv_font_montserrat_18
#define F_PAGE  &lv_font_montserrat_20
#define F_CLOCK &lv_font_montserrat_22
#define F_HERO  &lv_font_montserrat_46

#define RELAY_COUNT  4
#define SCENE_COUNT  4
#define HISTORY_MAX  8
#define REG_MAX      420

static constexpr uint32_t TOUCH_GUARD_MS = 180;
static constexpr uint32_t RELAY_PENDING_TIMEOUT_MS = 2500;
static constexpr uint32_t RELAY_OFFLINE_TIMEOUT_MS = 15000;
static constexpr uint32_t STATUS_REQUEST_INTERVAL_MS = 5000;
static constexpr uint32_t WEATHER_INTERVAL_MS = 10UL * 60UL * 1000UL;
static constexpr uint32_t WEATHER_RETRY_MS = 60UL * 1000UL;
static constexpr uint8_t RELAY_MASK_ALL = (1U << RELAY_COUNT) - 1;

static const uint8_t RELAY_ESP32_MAC[6] = {0xC0, 0x5D, 0x89, 0xF5, 0xAD, 0xFC};

/* =========================================================
   THEME PALETTES
   ========================================================= */
struct Palette {
    uint32_t bg, chrome, card, raised, sunken, border;
    uint32_t text, text2, text3;
    uint32_t accent, accent_soft, accent_bay, accent_line, accent_hi;
    uint32_t amber, violet, green, coral;
    uint32_t chart_past, grid, knob_off, icon_off;
    uint32_t nav_on[4];
    uint32_t relay_on[RELAY_COUNT];
    uint32_t scene_fg[SCENE_COUNT];
    uint32_t scene_soft[SCENE_COUNT];
    uint32_t scene_line[SCENE_COUNT];
};

enum { THEME_SLATE = 0, THEME_AMOLED = 1, THEME_AURORA = 2, THEME_COUNT = 3 };

static const Palette palettes[THEME_COUNT] = {
    /* ---- Slate: the original graphite look, with lifted greys for contrast ---- */
    {
        0x0D1117, 0x121821, 0x18202A, 0x202A36, 0x10161F, 0x2A3644,
        0xF3F6F8, 0xA9B6C4, 0x8A97A8,
        0x4E9BFF, 0x142232, 0x1D3B60, 0x335D8A, 0x7DB6FF,
        0xFFB84D, 0x8D8BEB, 0x61C786, 0xE4676B,
        0x8A97A8, 0x263341, 0x8A97A8, 0xA9B6C4,
        {0x7DB6FF, 0x7DB6FF, 0x7DB6FF, 0x7DB6FF},
        {0x7DB6FF, 0x7DB6FF, 0x7DB6FF, 0x7DB6FF},
        {0x7DB6FF, 0x8D8BEB, 0xFFB84D, 0xE4676B},
        {0x142232, 0x212038, 0x2A2218, 0x321A1E},
        {0x335D8A, 0x4A4785, 0x5C4325, 0x6E2D33},
    },
    /* ---- AMOLED: true black chrome for the panel's deepest state ---- */
    {
        0x000000, 0x07090C, 0x0F141A, 0x171E26, 0x05070A, 0x263039,
        0xFFFFFF, 0xB2BECB, 0x94A1AF,
        0x4E9BFF, 0x0E1A28, 0x16324F, 0x2F5680, 0x8CC0FF,
        0xFFC163, 0x9B99F5, 0x6FD494, 0xF07178,
        0x94A1AF, 0x1B242C, 0x94A1AF, 0xB2BECB,
        {0x8CC0FF, 0x8CC0FF, 0x8CC0FF, 0x8CC0FF},
        {0x8CC0FF, 0x8CC0FF, 0x8CC0FF, 0x8CC0FF},
        {0x8CC0FF, 0x9B99F5, 0xFFC163, 0xF07178},
        {0x0E1A28, 0x15142A, 0x231C12, 0x2A1216},
        {0x2F5680, 0x413E77, 0x543D22, 0x63272D},
    },
    /* ---- Aurora: deep navy with cyan/violet accents and per-icon hues ---- */
    {
        0x08111F, 0x101A33, 0x18284C, 0x223862, 0x0C1830, 0x315582,
        0xF8FAFF, 0xA9B7D0, 0x8C9CBA,
        0x32D5FF, 0x123A55, 0x1B4E6E, 0x2F7FA5, 0x7FE6FF,
        0xFFBF47, 0xA277FF, 0x4ADE80, 0xFF5D73,
        0x8C9CBA, 0x1E3559, 0x8C9CBA, 0x8C9CBA,
        {0x32D5FF, 0xFFBF47, 0xA277FF, 0x4ADE80},
        {0xFFE066, 0xFF9F4A, 0x32D5FF, 0x4ADE80},
        {0x32D5FF, 0xA277FF, 0xFFBF47, 0xFF5D73},
        {0x123A55, 0x2A2050, 0x3A2E14, 0x3A1723},
        {0x2F7FA5, 0x5B45A5, 0x7A5C24, 0x8A3140},
    },
};

/* Style roles. Every themed widget is tagged with one at creation time so a
   theme switch can repaint the whole tree without rebuilding it. */
enum {
    R_NONE = 0, R_SCREEN, R_CHROME, R_CARD, R_RAISED, R_SUNKEN, R_DIVIDER,
    R_TXT, R_TXT2, R_TXT3, R_TXT_AMBER, R_TXT_ACCENT,
    R_GRID, R_ARC, R_AMBER_FILL, R_ACCENT_FILL, R_ACCENT_RING, R_PAST_FILL,
    R_ICON_AMBER, R_ICON_GREEN,
    R_SLIDER, R_SWITCH, R_SEG_GROUP, R_SEG_BTN,
};

/* =========================================================
   PERSISTED SETTINGS (NVS namespace + keys are all <= 15 chars)
   ========================================================= */
struct Settings {
    uint8_t brightness;   /* 15..100 */
    uint8_t theme;        /* 0..2 */
    uint8_t unit;         /* 0 = Celsius, 1 = Fahrenheit */
    uint16_t dim_sec;     /* 0 = off, else 30 / 60 */
    uint16_t sleep_sec;   /* 0 = never, else 120 / 300 */
    bool show_indoor;
    bool show_date;
    bool show_scenes;
};

static Settings settings = {80, THEME_SLATE, 0, 30, 120, true, true, true};
static Preferences prefs;
static volatile bool settings_dirty = false;
static uint32_t settings_dirty_at = 0;

static const uint16_t dim_values[3] = {0, 30, 60};
static const uint16_t sleep_values[3] = {120, 300, 0};

/* =========================================================
   LIVE MODELS
   ========================================================= */
struct RelayDef {
    const char *name;
    const char *sub;
    const char *log_name;
    const lv_img_dsc_t *icon;
};

static const RelayDef relay_defs[RELAY_COUNT] = {
    {"Living Room", "Ceiling Light" MDOT "Relay 1",    "Living Room",  &icon_lightbulb_24},
    {"Kitchen",     "Pendant Lamp" MDOT "Relay 2",     "Kitchen Lamp", &icon_lamp_desk_24},
    {"Main Fan",    "Circulation" MDOT "Relay 3",      "Main Fan",     &icon_fan_24},
    {"Garden",      "Irrigation Valve" MDOT "Relay 4", "Garden Valve", &icon_sprout_24},
};

struct SceneDef {
    const char *name;
    const lv_img_dsc_t *icon;
    bool states[RELAY_COUNT];
};
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
